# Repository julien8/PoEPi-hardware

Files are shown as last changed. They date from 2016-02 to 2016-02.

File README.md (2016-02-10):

## Raspberry Pi Zero - PoEPi

The Raspberry Pi Zero is a low power and low footprint Raspberry Pi. It gives people an opportunity to move towards compact connected devices
while moving away from being a just a small computer. PiPoE adds a new way of connecting the Raspberry Pi Zero with the world in a very efficient
manner. Power over Ethernet is a way if injecting power into an Ethernet cable without interfering with the data. What it gives you is a high 
reliability way of powering and communicating with the Raspberry Pi. The design of PoEPi is open source under the CERN OHL V1.2 and can be easily
adapted to your own custom designs. 

For more information check out the Wiki on github

### Basic Hardware usage

1. Setup your Raspberry Pi with a monitor and enable SSH with raspi-config
2. Plug Ethernet cable into a PoE switch or add a PoE injector somehwhere in you Ethernet line
3. Connect the PoEPi to the Raspberry Pi
4. Plug in the "injected" Ethernet cable
5. The Pi Zero should be powered and you then SSH into the Pi

For information on the particular PoEPi modules and how to control them please see the wiki on the github page

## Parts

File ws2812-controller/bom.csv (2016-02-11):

ref | value | footprint | Mouser Part No. | Quantity
C1 C7 C8 C9 C10 C19 C18 C21 C15 C16 | 0.1uf | w_smd_cap:c_0402 | 710-885012105001 | 10
C11 | 10uf | w_smd_cap:c_0603 | 81-ZRB18AR61C106ME1L | 1
C12 | CP | w_smd_cap:c_elec_4x4.5 | 667-EEE-1AA330WR | 1
C13 | 2nf | w_smd_cap:c_0603 | 81-GRM1885C1H202JA1D | 1
C14 | 6.8nf | w_smd_cap:c_0402 | 81-GRM155R71H682KA8D | 1
C17 | CP | w_smd_cap:c_elec_8x6.5 | 667-EEE-1AA221P | 1
C2 C3 | 16pf | w_smd_cap:c_0402 | 81-GRM1555C1H160JA1D | 2
C20 | 1uf | w_smd_cap:c_0402 | 810-C1005X5R1H104K | 1
C22 | 1uf | w_smd_cap:c_0805 | 810-C2012X7S2A105K | 1
C4 | 220uf | w_smd_cap:c_tant_B | 581-TAJB475K025R | 1
C5 | 6.8uf | w_smd_cap:c_tant_D | 74-293D685X9050D2TE3 | 1
D1 D2 | BRIDGE | w_smd_diode:MBS | 621-HD01-T | 2
D3 | ZENER | w_smd_diode:do214ac | 576-SMAJ58A | 1
D4 | BAS516 | w_smd_diode:sod523 | 771-BAS516-T/R | 1
D5 | D_Schottky | w_smd_diode:do214ab | 621-B360A-F | 1
D6 | LED | w_smd_leds:Led_0603 | 743-HT-191USD | 1
D7 | ZENER | w_smd_diode:sod123 | 771-BZT52HB5V1115 | 1
IC1 | ENC28J60-I/ML | w_smd_qfn:qfn-28 | 579-ENC28J60-I/ML | 1
J1 | RJ45-LED | w_conn_pc:rj45-tyco-2-406549-7 | 710-615008137421 | 1
L1 | 2.2uH | w_smd_inductors:inductor_smd_1008 | 81-LQM2HPN2R2MEHL | 1
L2 | BEAD | w_smd_inductors:inductor_smd_0402 | 81-BLM15AG102SN1D | 1
Q1 | SI3440DV | w_smd_trans:tsot-6 | 781-SI3440DV-E3 | 1
Q2 | BSS138 | w_smd_trans:sot23 | 621-DMG2305UX-13 | 1
Q3 | BSS138 | w_smd_trans:sot23 | 512-BSS138 | 1
R12 | 3.3k | w_smd_resistors:r_0402 | 754-RR0510P-332D | 1
R13 | 390 | w_smd_resistors:r_0402 | 594-MCT06030C3900FP5 | 1
R14 R16 R17 R26 | 49.9 | w_smd_resistors:r_0402 | 660-RK73H1ETQTP49R9F | 4
R15 | 240 | w_smd_resistors:r_0402 | 754-RR0816P-241D | 1
R18 | 360 | w_smd_resistors:r_0402 | 71-CRCW0603316RFKEB | 1
R19 | 10k | w_smd_resistors:r_0402 | 71-CRCW0402-10K-E3 | 1
R2 R4 R10 R11 | 10k | w_smd_resistors:r_0402 | 754-RR0510P-103D | 4
R20 | 47k | w_smd_resistors:r_0402 | 667-ERJ-2RKF4702X | 1
R21 R22 | 549 | w_smd_resistors:r_0402 | 667-ERJ-2RKF5490X | 2
R24 R23 | 14k | w_smd_resistors:r_0402 | 667-ERJ-2RKF1402X | 2
R25 | 100 | w_smd_resistors:r_0402 | 71-CRCW0402-100-E3 | 1
R3 | 1k | w_smd_resistors:r_0402 | 754-RR0510P-102D | 1
R6 | 0.05 | w_smd_resistors:r_1206 | 660-UR732BTTD50L0F | 1
R7 | 6.8k | w_smd_resistors:r_0402 | 754-RR0510P-682D | 1
R8 | 2.32k | w_smd_resistors:r_0402 | 667-ERJ-2RKF2321X | 1
T1 | PULSE_H1197 | project_foot:H2019 | 673-H1197FNL | 1
T2 | TRANSFO | project_foot:PoE_TRANS | 710-7491199501 | 1
T3 | VOLTAGE_REF | w_smd_trans:sot23 | 863-TLV431BSN1T1G | 1
U2 | PAS291 | project_foot:OPTO_ISO | 551-PS2911-1-K-AX | 1
U3 | LM1117IMPX-ADJ | w_smd_trans:sot223 | 926-M1117IMPXADJNOPB | 1
U5 | DMMT5401 | w_smd_trans:sot23-6 | 621-DMMT5401-7-F | 1
Y1 | 25Mhz | w_crystal:crystal_smd_5x3.2mm | 774-445I23D25M00000 | 1

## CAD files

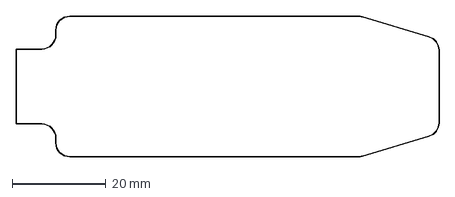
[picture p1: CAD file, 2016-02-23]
servo-controller/board_edge.dxf
90.3 x 30.0 mm

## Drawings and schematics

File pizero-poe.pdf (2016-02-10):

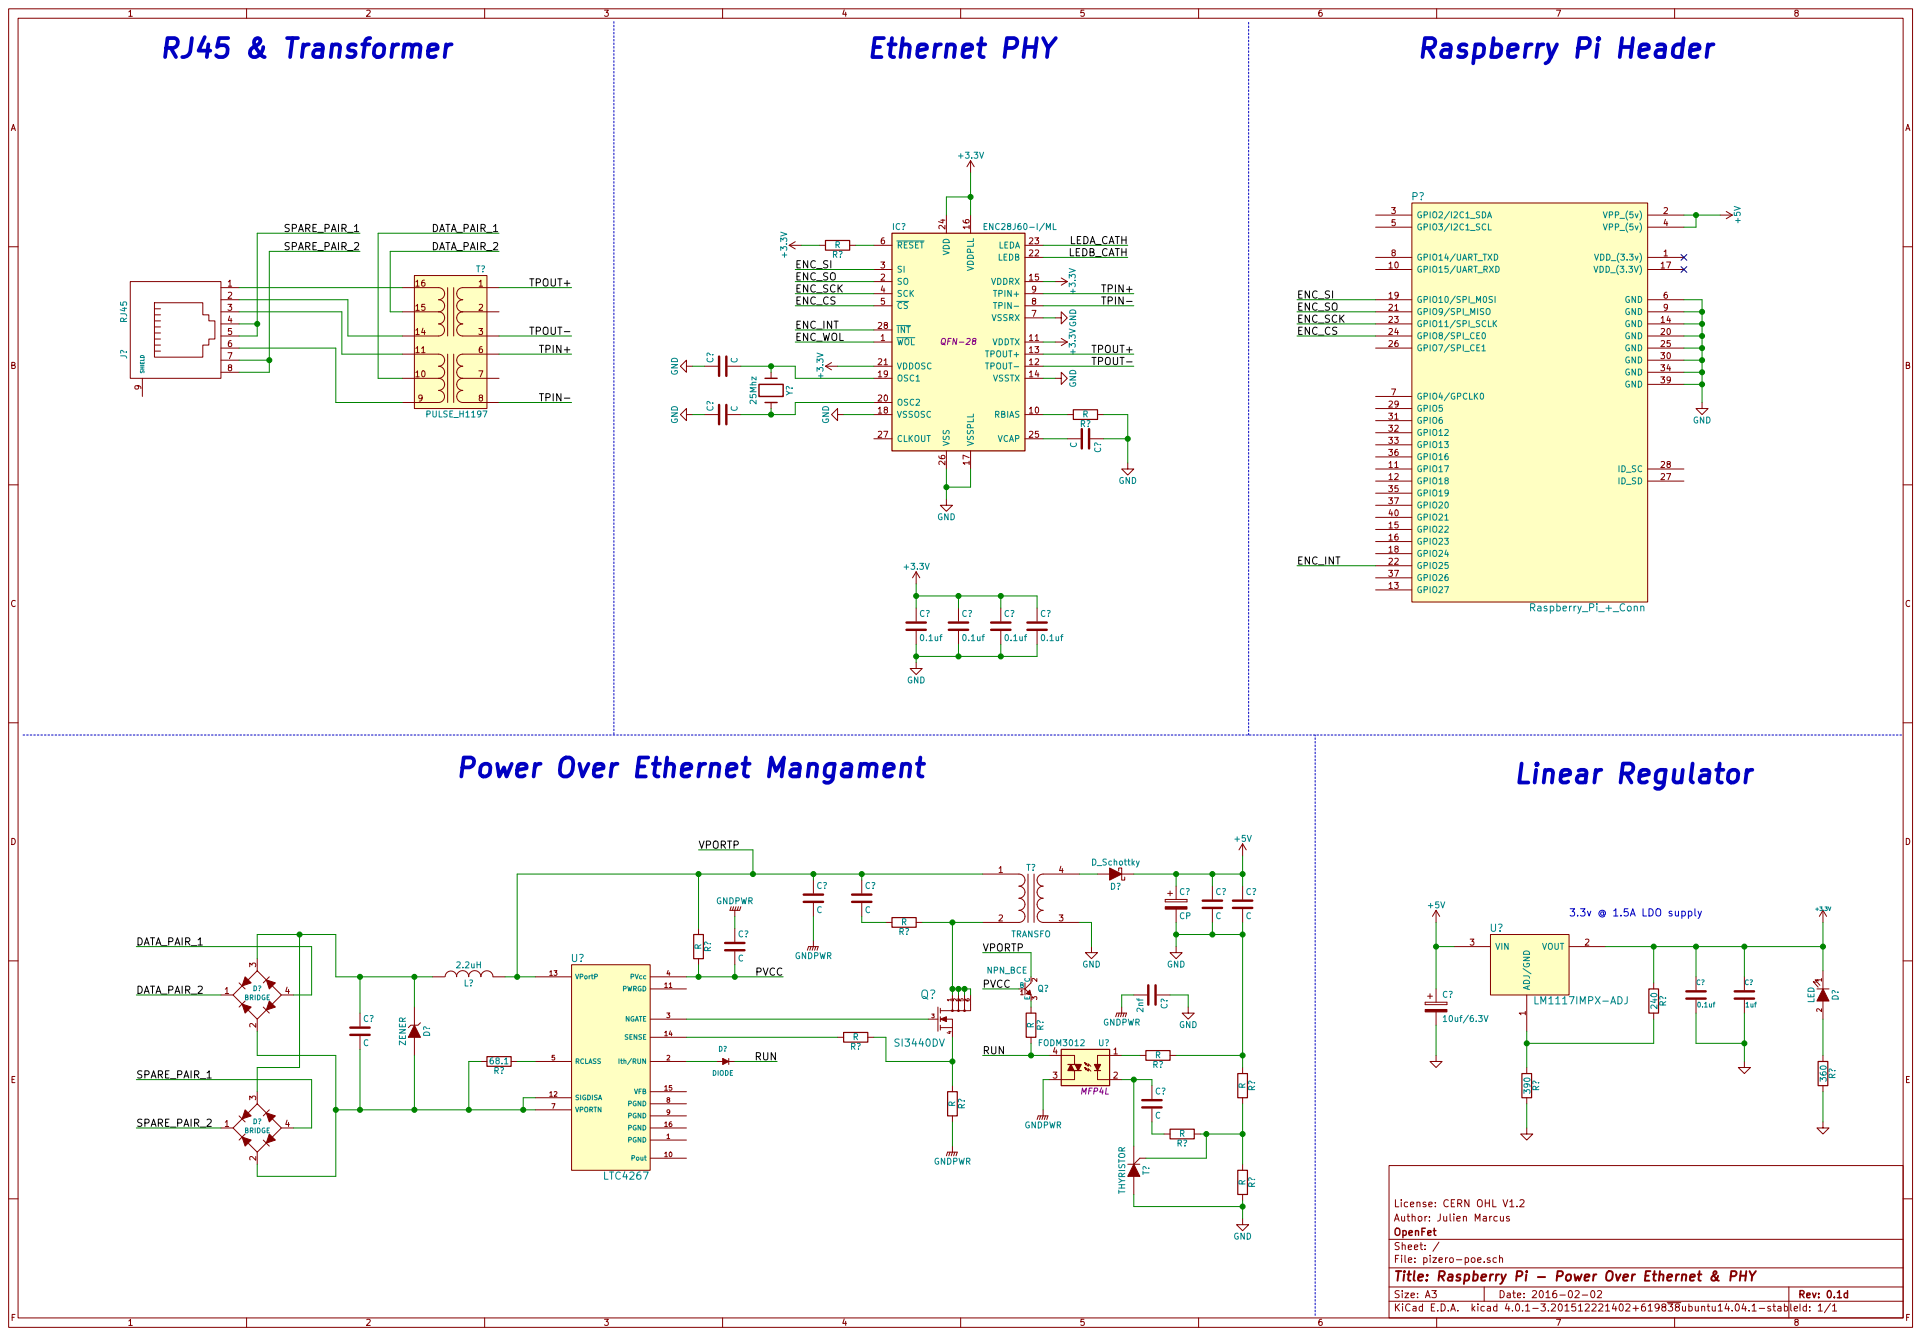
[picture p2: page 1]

File: pizero-poe.sch Sheet: / OpenFet Author: Julien Marcus License: CERN OHL V1.2

Id: 1/1 Title: Raspberry Pi - Power Over Ethernet & PHY

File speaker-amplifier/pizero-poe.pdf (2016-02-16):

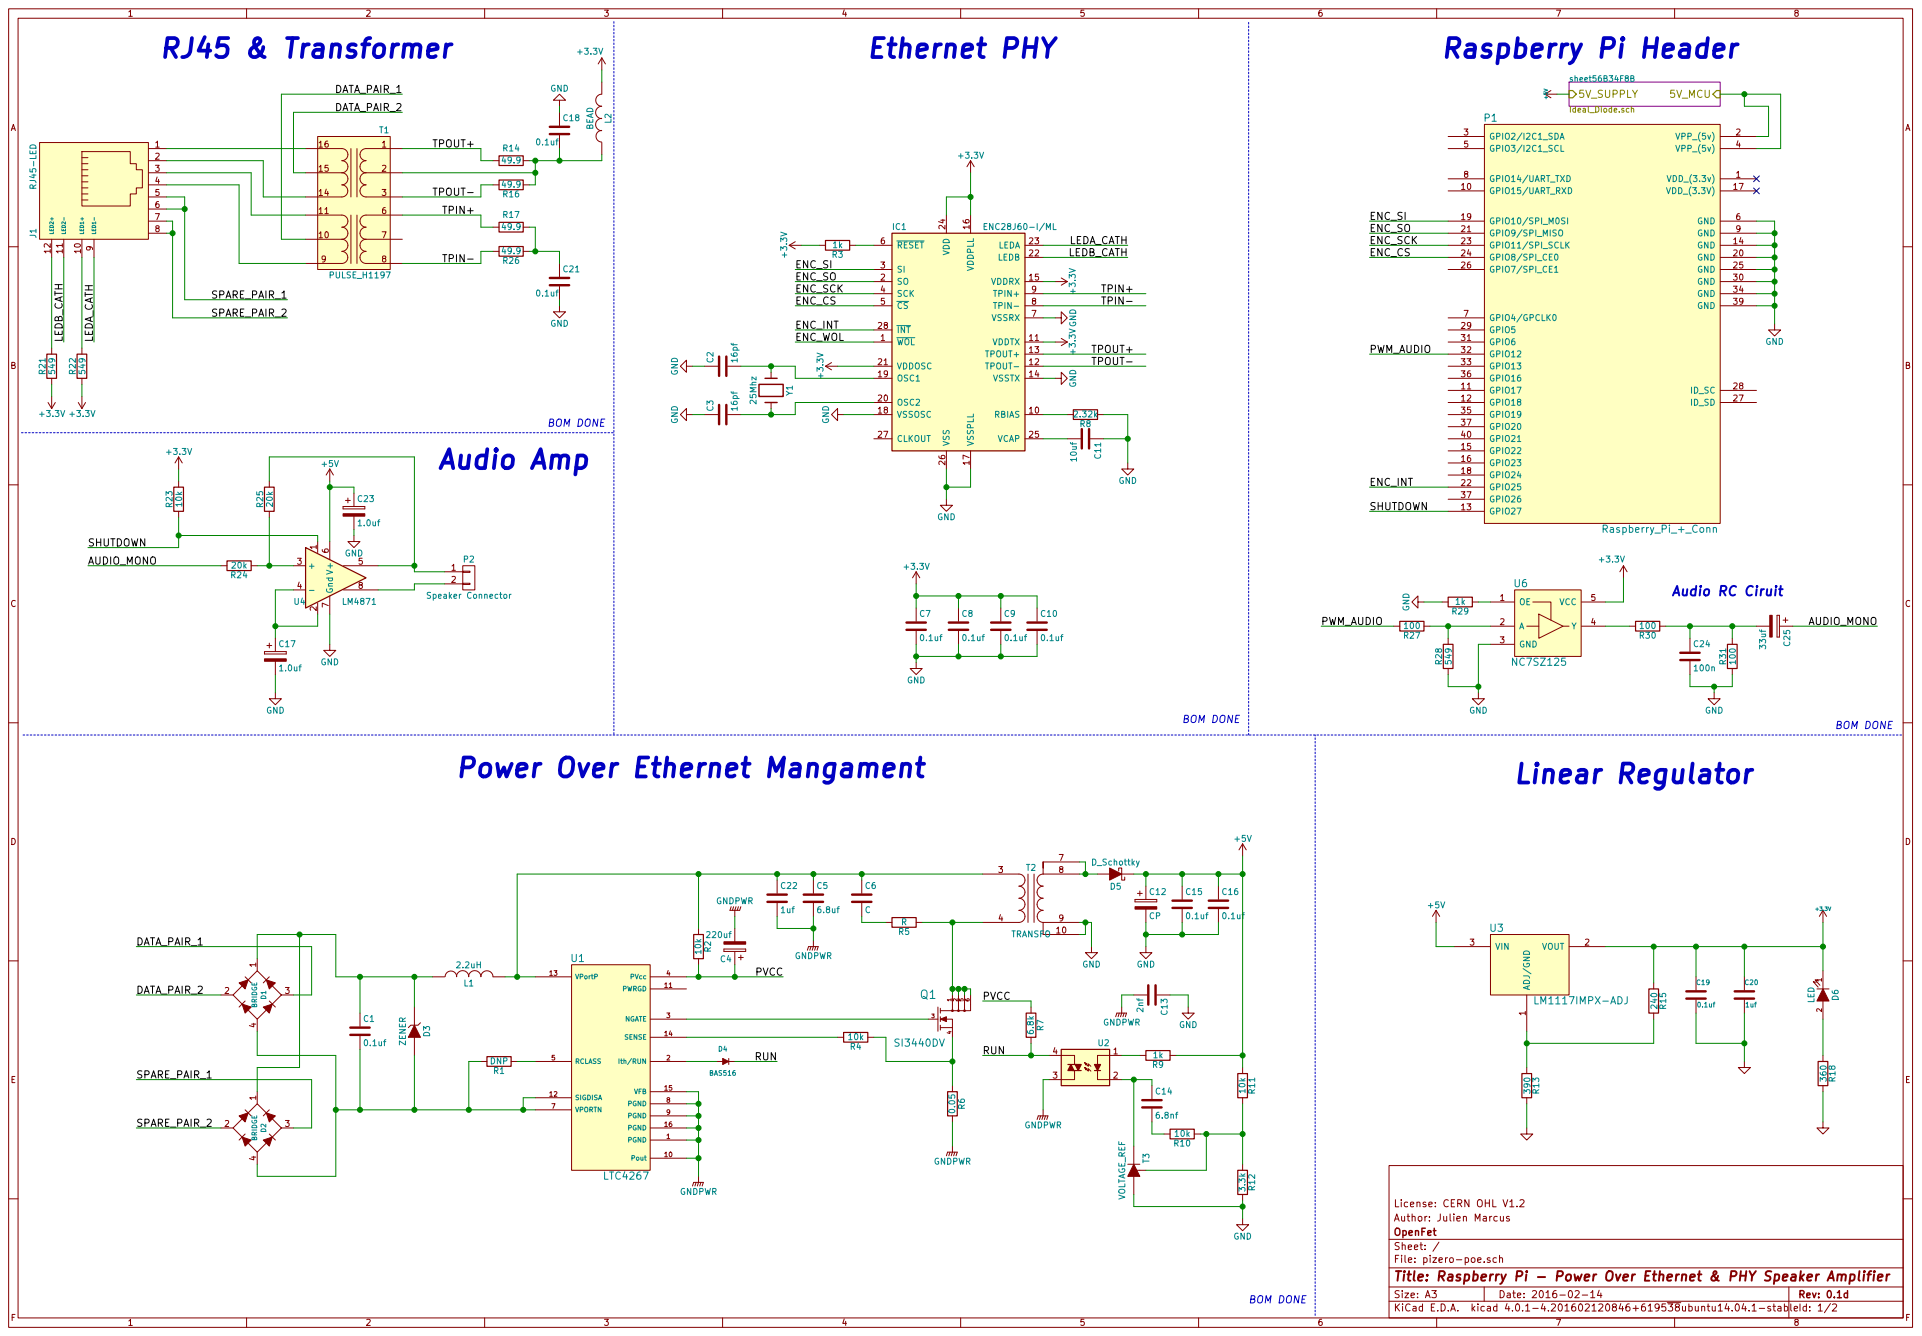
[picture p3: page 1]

File: pizero-poe.sch Sheet: / OpenFet Author: Julien Marcus License: CERN OHL V1.2

Id: 1/2 Title: Raspberry Pi - Power Over Ethernet & PHY Speaker Amplifier

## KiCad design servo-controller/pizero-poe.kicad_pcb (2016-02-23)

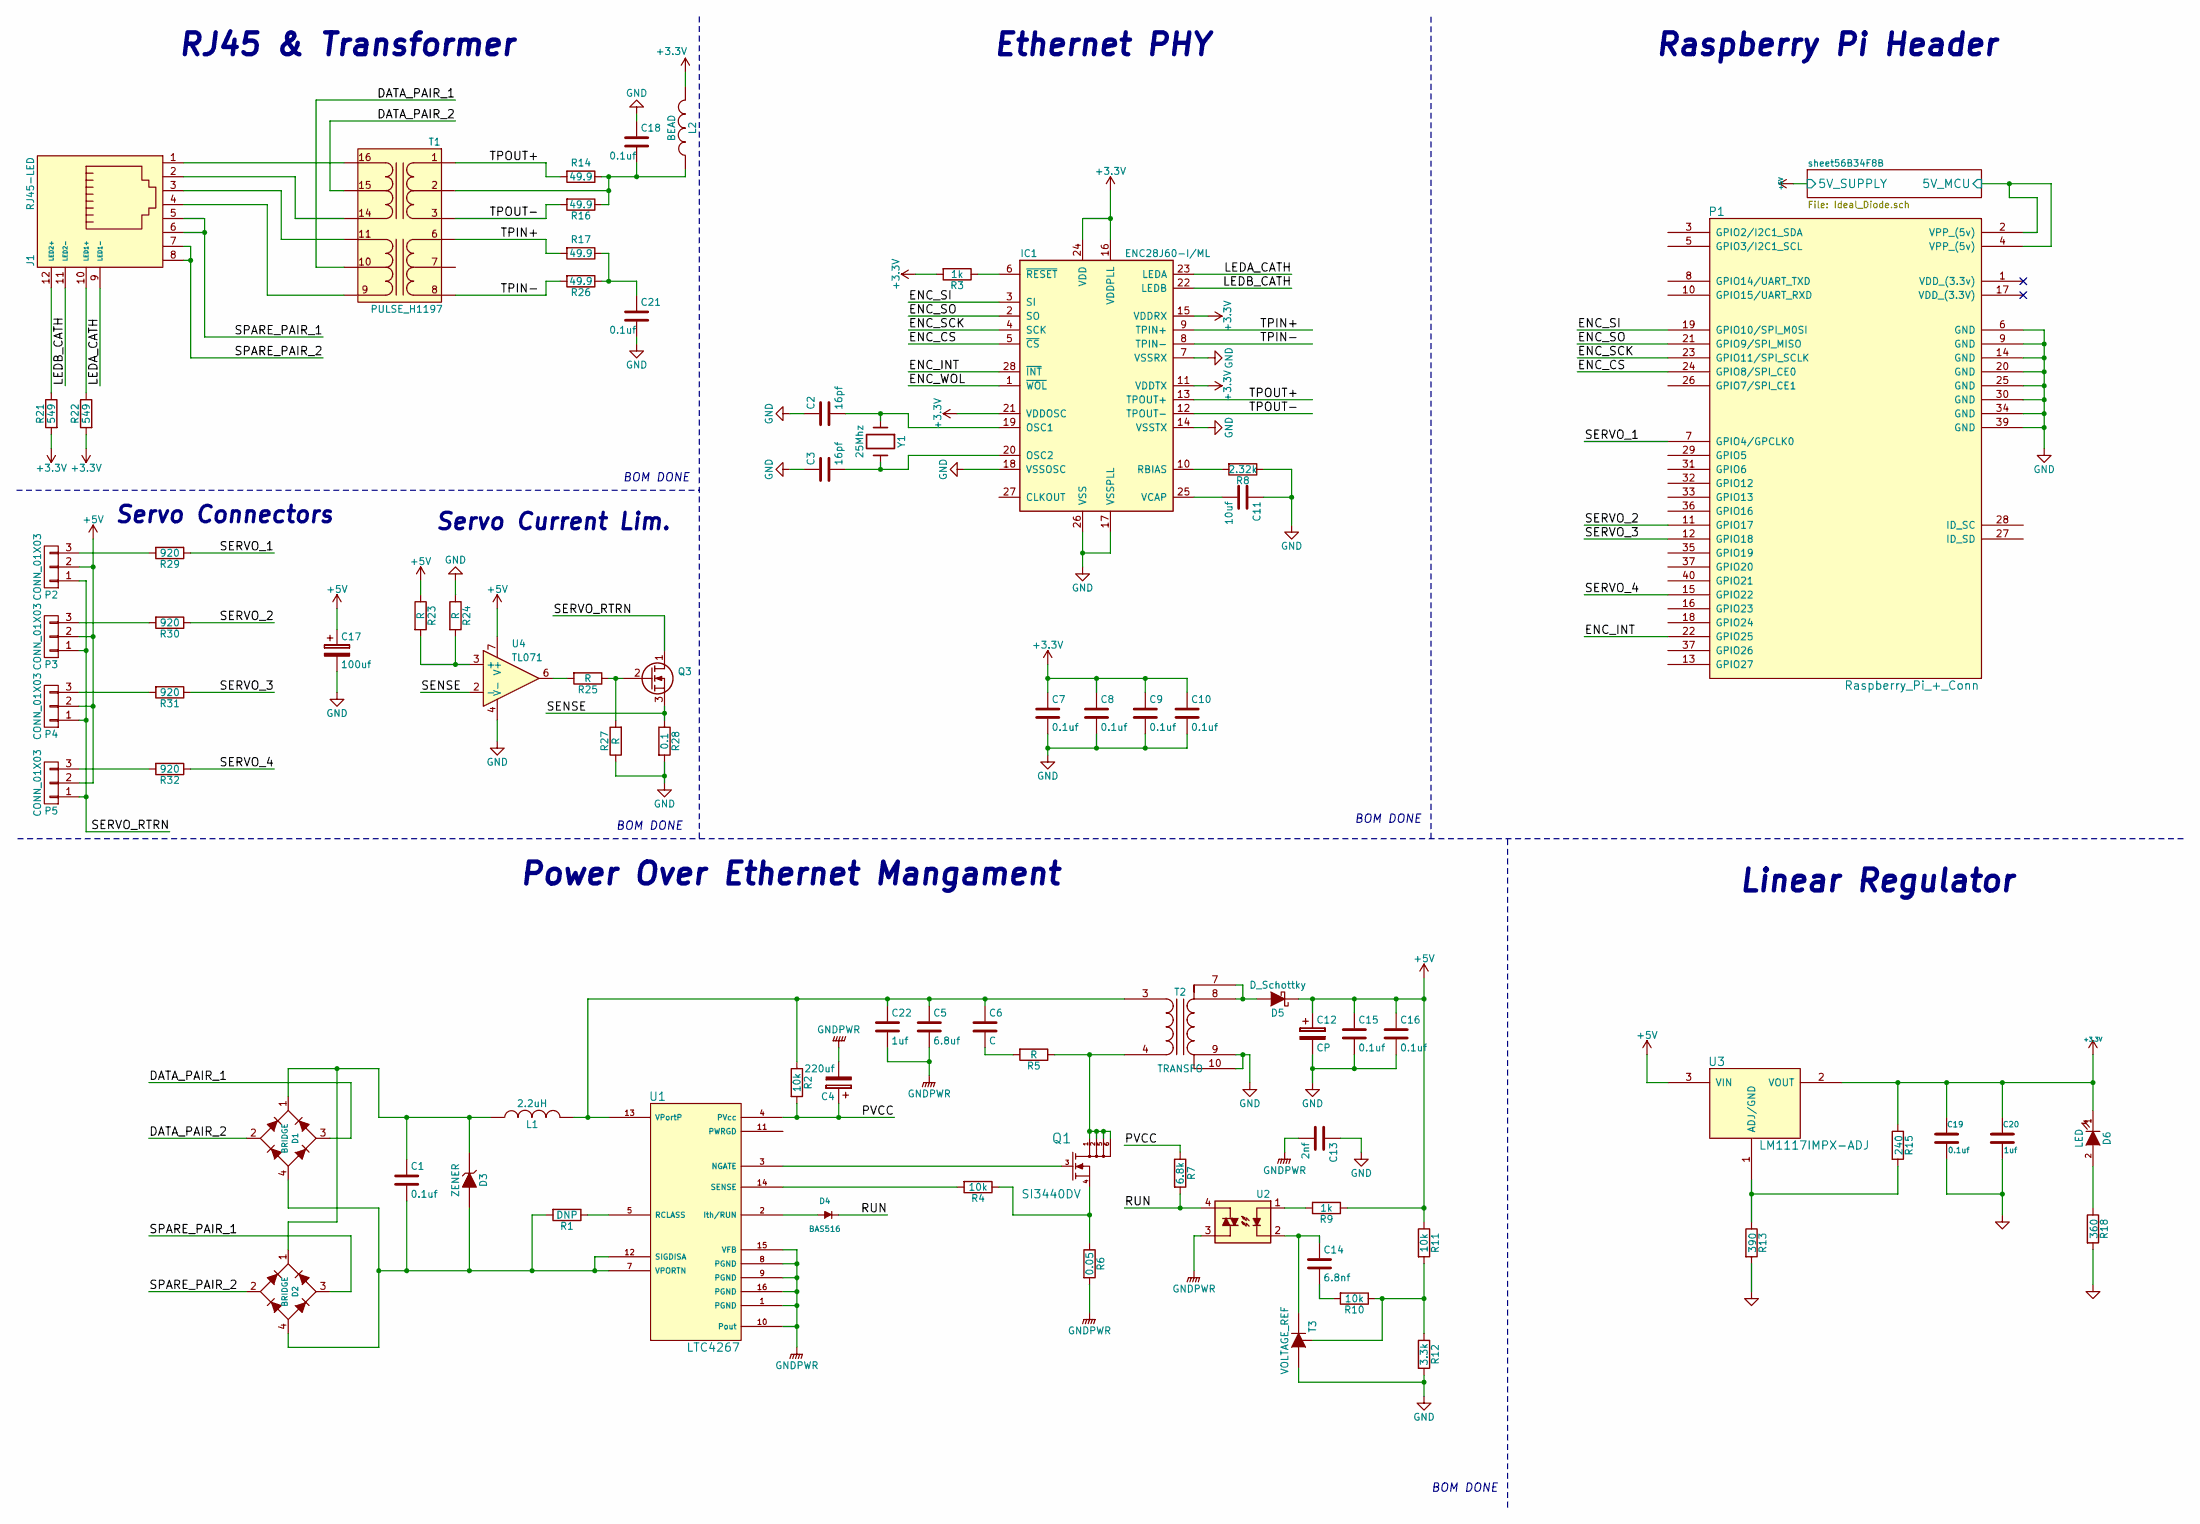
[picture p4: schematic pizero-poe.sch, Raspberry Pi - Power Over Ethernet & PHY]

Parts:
C1, C7, C8, C9, C18, C19, C21: 0.1uf; c_0402; Mouser Part No. 710-885012105001
C2, C3: 16pf; c_0402; Mouser Part No. 81-GRM1555C1H160JA1D
C4: 220uf; c_tant_B; Mouser Part No. 581-TAJB475K025R
C5: 6.8uf; c_tant_D; Mouser Part No. 74-293D685X9050D2TE3
C6: C; c_0402
C10, C15, C16: 0.1uf; c_0603; Mouser Part No. 710-885012105001
C11: 10uf; c_0603; Mouser Part No. 81-ZRB18AR61C106ME1L
C12: CP; c_elec_4x4.5; Mouser Part No. 667-EEE-1AA330WR
C13: 2nf; c_0603; Mouser Part No. 81-GRM1885C1H202JA1D
C14: 6.8nf; c_0402; Mouser Part No. 81-GRM155R71H682KA8D
C17: 100uf; c_elec_8x6.5
C20: 1uf; c_0402; Mouser Part No. 810-C1005X5R1H104K
C22: 1uf; c_0805; Mouser Part No. 810-C2012X7S2A105K
D1, D2: BRIDGE; MBS; Mouser Part No. 621-HD01-T
D3: ZENER; do214ac; Mouser Part No. 576-SMAJ58A
D4: BAS516; sod523; Mouser Part No. 771-BAS516-T/R
D5: D_Schottky; do214ab; Mouser Part No. 621-B360A-F
D6: LED; Led_0603; Mouser Part No. 743-HT-191USD
IC1: ENC28J60-I/ML; qfn-28; Mouser Part No. 579-ENC28J60-I/ML
J1: RJ45-LED; rj45-tyco-2-406549-7; Mouser Part No. 710-615008137421
L1: 2.2uH; inductor_smd_1008; Mouser Part No. 81-LQM2HPN2R2MEHL
L2: BEAD; inductor_smd_0402; Mouser Part No. 81-BLM15AG102SN1D
P1: Raspberry_Pi_+_Conn
P2, P3, P4, P5: CONN_01X03; pin_strip_3
Q1: SI3440DV; tsot-6; Mouser Part No. 781-SI3440DV-E3
Q3: Q_NMOS_DGS; d-pak
R1: DNP; r_0402
R2, R4, R10, R11: 10k; r_0402; Mouser Part No. 754-RR0510P-103D
R3: 1k; r_0402; Mouser Part No. 754-RR0510P-102D
R5, R23, R24, R25, R27: R; r_0402
R6: 0.05; r_1206; Mouser Part No. 660-UR732BTTD50L0F
R7: 6.8k; r_0402; Mouser Part No. 754-RR0510P-682D
R8: 2.32k; r_0402; Mouser Part No. 667-ERJ-2RKF2321X
R9: 1k; r_0402
R12: 3.3k; r_0402; Mouser Part No. 754-RR0510P-332D
R13: 390; r_0402; Mouser Part No. 594-MCT06030C3900FP5
R14, R16, R17, R26: 49.9; r_0402; Mouser Part No. 660-RK73H1ETQTP49R9F
R15: 240; r_0402; Mouser Part No. 754-RR0816P-241D
R18: 360; r_0402; Mouser Part No. 71-CRCW0603316RFKEB
R21, R22: 549; r_0402; Mouser Part No. 667-ERJ-2RKF5490X
R28: 0.1; r_1210
R29, R30, R31, R32: 920; r_0402
T1: PULSE_H1197; H2019; Mouser Part No. 673-H1197FNL
T2: TRANSFO; PoE_TRANS; Mouser Part No. 710-7491199501
T3: VOLTAGE_REF; sot23; Mouser Part No. 863-TLV431BSN1T1G
U1: LTC4267; ssop-16; Digikey Part No. LTC4267CGN-3#PBF-ND
U2: PAS291; OPTO_ISO; Mouser Part No. 551-PS2911-1-K-AX
U3: LM1117IMPX-ADJ; sot223; Mouser Part No. 926-M1117IMPXADJNOPB
U4: TL071; so-8
Y1: 25Mhz; crystal_smd_5x3.2mm; Mouser Part No. 774-445I23D25M00000

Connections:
+3V3: C7.1, C8.1, C9.1, C10.1, C19.1, C20.1, D6.1 (K), IC1.11 (VDDTX), IC1.15 (VDDRX), IC1.16 (VDDPLL), IC1.21 (VDDOSC), IC1.24 (VDD), L2.2, R3.2, R15.1, R21.2, R22.2, U3.2 (VOUT)
+5V: C12.1, C15.1, C16.1, C17.1, D5.1 (K), P2.2, P3.2, P4.2, P5.2, R9.1, R11.1, R23.1, U3.3 (VIN), U4.7 (V+); also elsewhere on the board
/DATA_PAIR_1: D1.3 (~2), T1.10
/DATA_PAIR_2: D1.2 (~1), T1.15
/ENC_CS: IC1.5 (~CS), P1.24 (GPIO8/SPI_CE0)
/ENC_INT: IC1.28 (~INT), P1.22 (GPIO25)
/ENC_SCK: IC1.4 (SCK), P1.23 (GPIO11/SPI_SCLK)
/ENC_SI: IC1.3 (SI), P1.19 (GPIO10/SPI_M0SI)
/ENC_SO: IC1.2 (SO), P1.21 (GPIO9/SPI_MISO)
/ENC_WOL: IC1.1 (~WOL)
/LEDA_CATH: IC1.23 (LEDA), J1.9 (LED1-)
/LEDB_CATH: IC1.22 (LEDB), J1.11 (LED2-)
/PVCC: C4.1, R2.2, R7.1, U1.4 (PVcc)
/RUN: D4.2 (K), R7.2, U2.4
/SENSE: Q3.3 (S), R28.1, U4.2 (-)
/SERVO_1: P1.7 (GPIO4/GPCLK0), R29.1
/SERVO_2: P1.11 (GPIO17), R30.1
/SERVO_3: P1.12 (GPIO18), R31.1
/SERVO_4: P1.15 (GPIO22), R32.1
/SERVO_RTRN: P2.1, P3.1, P4.1, P5.1, Q3.1 (D)
/SPARE_PAIR_1: D2.3 (~2), J1.5, J1.6
/SPARE_PAIR_2: D2.2 (~1), J1.7, J1.8
/TPIN+: IC1.9 (TPIN+), R17.2, T1.6 (PR1)
/TPIN-: IC1.8 (TPIN-), R26.2, T1.8 (PR2)
/TPOUT+: IC1.13 (TPOUT+), R14.2, T1.1 (PR1)
/TPOUT-: IC1.12 (TPOUT-), R16.2, T1.3 (PR2)
/sheet56B34F8B/5V_MCU: P1.2 (VPP_(5v)), P1.4 (VPP_(5v)); also elsewhere on the board
GND: C2.1, C3.1, C7.2, C8.2, C9.2, C10.2, C11.1, C12.2, C13.1, C15.2, C16.2, C17.2, C18.1, C19.2, C20.2, C21.2, IC1.7 (VSSRX), IC1.14 (VSSTX), IC1.17 (VSSPLL), IC1.18 (VSSOSC), IC1.26 (VSS), P1.6 (GND), P1.9 (GND), P1.14 (GND), P1.20 (GND), P1.25 (GND), P1.30 (GND), P1.34 (GND), P1.39 (GND), R8.1, R12.2, R13.2, R18.2, R24.1, R27.1, R28.2, T2.9 (SA), T2.10, T3.2 (A), U4.4 (V-); also elsewhere on the board
GNDPWR: C4.2, C5.2, C13.2, C22.2, R6.2, U1.1 (PGND), U1.8 (PGND), U1.9 (PGND), U1.10 (Pout), U1.15 (VFB), U1.16 (PGND), U2.3
unnamed: C1.1, D1.1 (V+), D2.1 (V+), D3.1 (K), L1.1
unnamed: C1.2, D1.4 (V-), D2.4 (V-), D3.2 (A), R1.2, U1.7 (VPORTN), U1.12 (SIGDISA)
unnamed: C2.2, IC1.19 (OSC1), Y1.1
unnamed: C3.2, IC1.20 (OSC2), Y1.2
unnamed: C6.2, R5.2
unnamed: C11.2, IC1.25 (VCAP)
unnamed: C14.1, T3.3 (K), U2.2
unnamed: C14.2, R10.2
unnamed: C18.2, L2.1, R14.1, R16.1, T1.2 (PM)
unnamed: C21.1, R17.1, R26.1
unnamed: C5.1, C6.1, C22.1, L1.2, R2.1, T2.3 (AA), U1.13 (VPortP)
unnamed: D4.1 (A), U1.2 (Ith/RUN)
unnamed: D5.2 (A), T2.7, T2.8 (SB)
unnamed: D6.2 (A), R18.1
unnamed: IC1.6 (~RESET), R3.1
unnamed: IC1.10 (RBIAS), R8.2
unnamed: J1.1, T1.16 (S2)
unnamed: J1.2, T1.14 (S1)
unnamed: J1.3, T1.11 (S2)
unnamed: J1.4, T1.9 (S1)
unnamed: J1.10 (LED1+), R22.1
unnamed: J1.12 (LED2+), R21.1
unnamed: P2.3, R29.2
unnamed: P3.3, R30.2
unnamed: P4.3, R31.2
unnamed: P5.3, R32.2
unnamed: Q1.1 (D), Q1.2 (D), Q1.5 (D), Q1.6 (D), R5.1, T2.4 (AB)
unnamed: Q1.3 (G), U1.3 (NGATE)
unnamed: Q1.4 (S), R4.1, R6.1
unnamed: Q3.2 (G), R25.1, R27.2
unnamed: R1.1, U1.5 (RCLASS)
unnamed: R4.2, U1.14 (SENSE)
unnamed: R9.2, U2.1
unnamed: R10.1, R11.2, R12.1, T3.1 (G)
unnamed: R13.1, R15.2, U3.1 (ADJ/GND)
unnamed: R23.2, R24.2, U4.3 (+)
unnamed: R25.2, U4.6

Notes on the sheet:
Linear Regulator
Power Over Ethernet Mangament
RJ45 & Transformer
Ethernet PHY
Raspberry Pi Header
BOM DONE
Servo Connectors
Servo Current Lim.

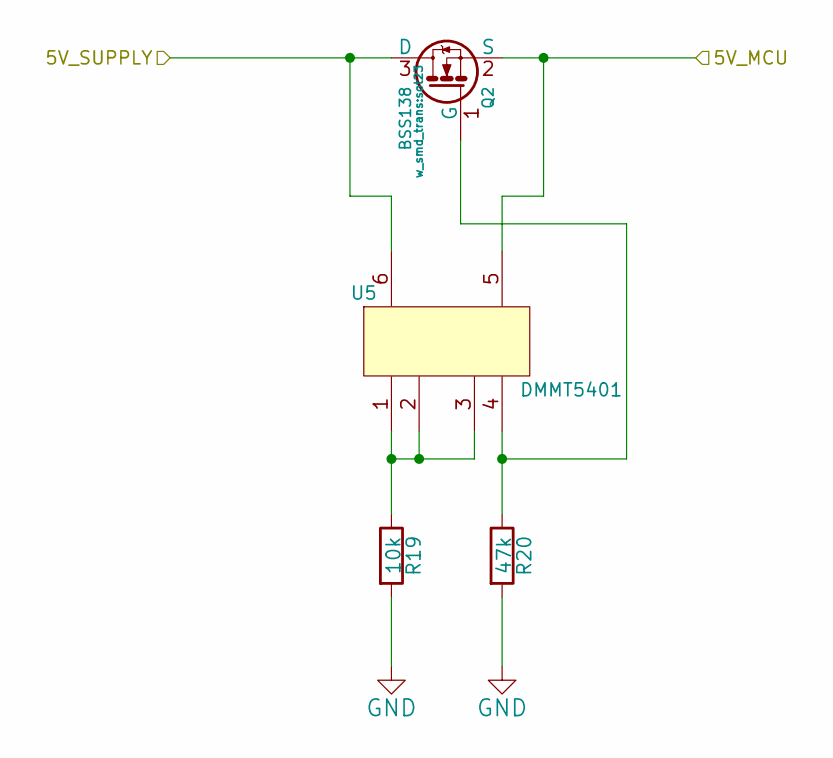
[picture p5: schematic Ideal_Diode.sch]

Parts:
Q2: BSS138; sot23; Mouser Part No. 621-DMG2305UX-13
R19: 10k; r_0402; Mouser Part No. 71-CRCW0402-10K-E3
R20: 47k; r_0402; Mouser Part No. 667-ERJ-2RKF4702X
U5: DMMT5401; sot23-6; Mouser Part No. 621-DMMT5401-7-F

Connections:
+5V: Q2.3 (D), U5.6; also elsewhere on the board
/sheet56B34F8B/5V_MCU: Q2.2 (S), U5.5; also elsewhere on the board
GND: R19.2, R20.2; also elsewhere on the board
unnamed: Q2.1 (G), R20.1, U5.4
unnamed: R19.1, U5.1, U5.2, U5.3

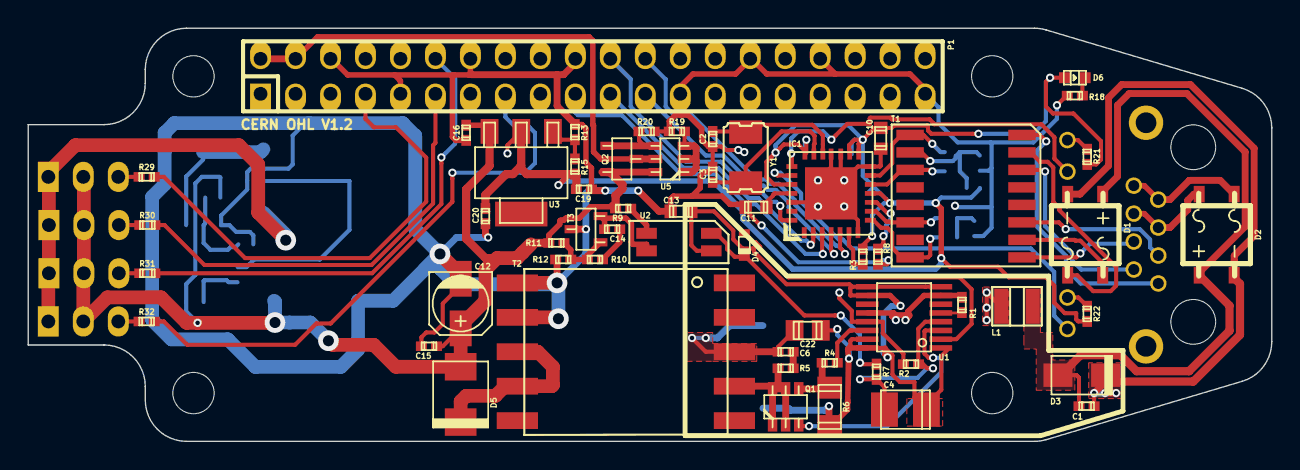
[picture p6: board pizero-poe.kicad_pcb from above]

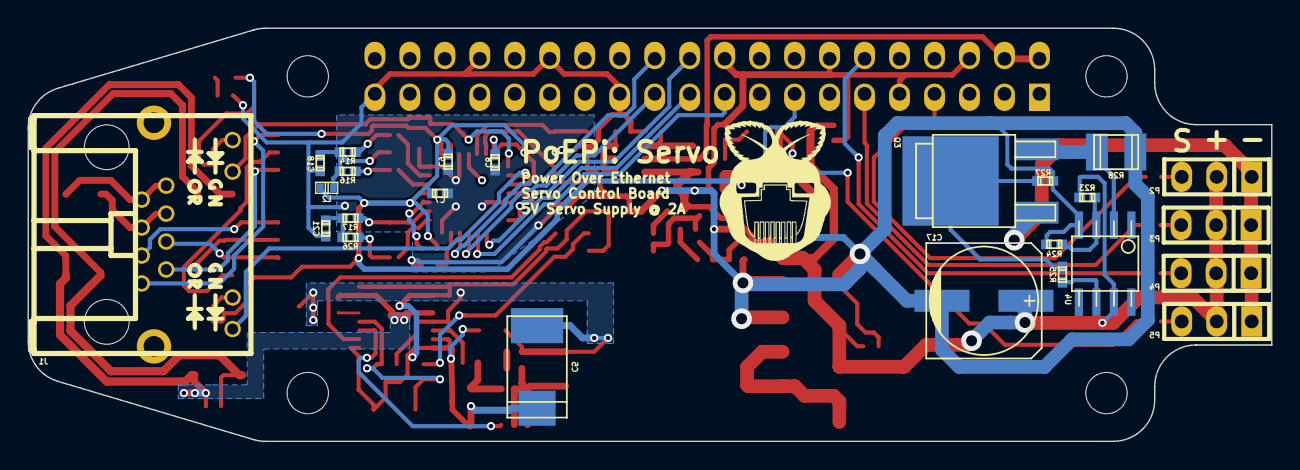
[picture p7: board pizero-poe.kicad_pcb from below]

Board: 2 copper layers, 90.3 x 30.0 mm, 85 parts (24 on the bottom side), 67 nets.

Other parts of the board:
MT1, MT2, MT3, MT4: MountingHole_3mm

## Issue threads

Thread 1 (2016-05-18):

What is the status of this project?

clickworkorange, 2016-05-18:
I was hoping to get some boards done but I'm unsure whether the current designs have been production tested yet, and whether there is a final BoM for any of them?

clickworkorange, 2016-06-07:
*cough*

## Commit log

2016-02-10 Intial commit of PoEPi
    [Ideal_Diode.sch, board_edge.dxf, pizero-poe.kicad_pcb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]
2016-02-11 changed cap size, wrong value
    [pizero-poe.kicad_pcb]
2016-02-11 added half of component part numbers
    [pizero-poe.sch]
2016-02-11 added EMI filtering on data lines
    [pizero-poe.sch]
2016-02-11 added EMI components after update
    [pizero-poe.kicad_pcb]
2016-02-11 changed caps after reviewing notes
    [pizero-poe.kicad_pcb, pizero-poe.sch]
2016-02-11 first complete development revision
    [Ideal_Diode.sch, bom.csv, pizero-poe.sch]
2016-02-16 initial commit of amplifier
    [Ideal_Diode.sch, board_edge.dxf, pizero-poe.kicad_pcb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]
2016-02-23 initial commit of servo board
    [Ideal_Diode.sch, board_edge.dxf, pizero-poe.kicad_pcb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]
